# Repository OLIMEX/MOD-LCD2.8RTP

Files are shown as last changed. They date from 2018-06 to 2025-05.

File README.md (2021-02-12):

# MOD-LCD2.8RTP
TFT COLOR LCD module with [UEXT connector](https://www.olimex.com/Products/Modules/) for
[ESP32-EVB](https://www.olimex.com/Products/IoT/ESP32/ESP32-EVB/open-source-hardware) and
[ESP32-POE](https://www.olimex.com/Products/IoT/ESP32/ESP32-POE/open-source-hardware)

**Using MOD-LCD2.8RTP requires non-standard SPI for the display and I2C for the touch screen** 

The non-standard part of the SPI is the lack of MISO which is Data/Command selection pin (refer to controller's datasheet) which has to be set as output.

UEXT pinout:

|UEXT column 1|UEXT column 2|Function|
|---|---|---|
|1 - 3.3V |2 - GND|Power pins|
|3 - NOT USED|4 - NOT USED|UART pins not used|
|5 - SCL|6 - SDA|I2C pins used for touch component|
|7 - D/C|8 - MOSI|SPI pins sans MISO used for display|
|9 - CLK|10 - CS|SPI CLK/CS for display|

If you are using I2C, then the RX wire can also be used to control the brightness. This requires midfying the SJ2 jumper. Refer to the schematic around FET1.

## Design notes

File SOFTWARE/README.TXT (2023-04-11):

##Arduino IDE example:

Tested with Olimex boards - OLIMEXINO-2560, OLIMEXINO-STM32F3, and Olimex ESP32 boards (Olimex ESP32-EVB, ESP32-POE, ESP32-POE-ISO). Refer to the comments in the .ino sketch - make sure to download all the files (library and header files; and not just the .ino).

Folder "graphicstest_olimex_NS2009" contains demo for NS2009 touchscreen.

Folder "graphicstest_olimex" contains demo for STMPE610 touchscreen component.

Basically if touch is not working try the demo in the other folder.

If you use the demo with an ESP32 boards remember to prepare your Arduino IDE environment according to the arduino for ESP32 repository here: https://github.com/espressif/arduino-esp32#installation-instructions

NOTE: You might need to edit the pins in board_pinout.h - for example, if you use ESP32-POE instead of ESP32-EVB, you need to change TFT_CS from 17 to 5 (since ESP32-POE uses pin #5 for chip select).

##PlatformIO example:

Made and tested with Olimex ESP32-EVB using PlatformIO 3.6.0a3

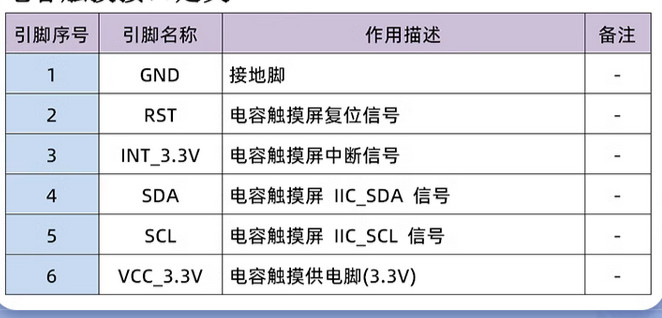
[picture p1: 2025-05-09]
HARDWARE/DOCS/LCD1-pinout2.jpg

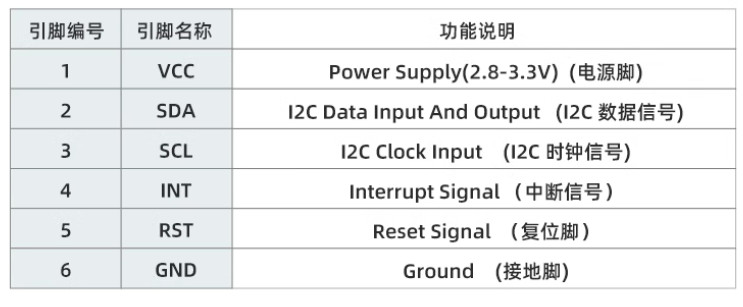
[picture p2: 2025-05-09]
HARDWARE/DOCS/LCD2-pinout2.jpg

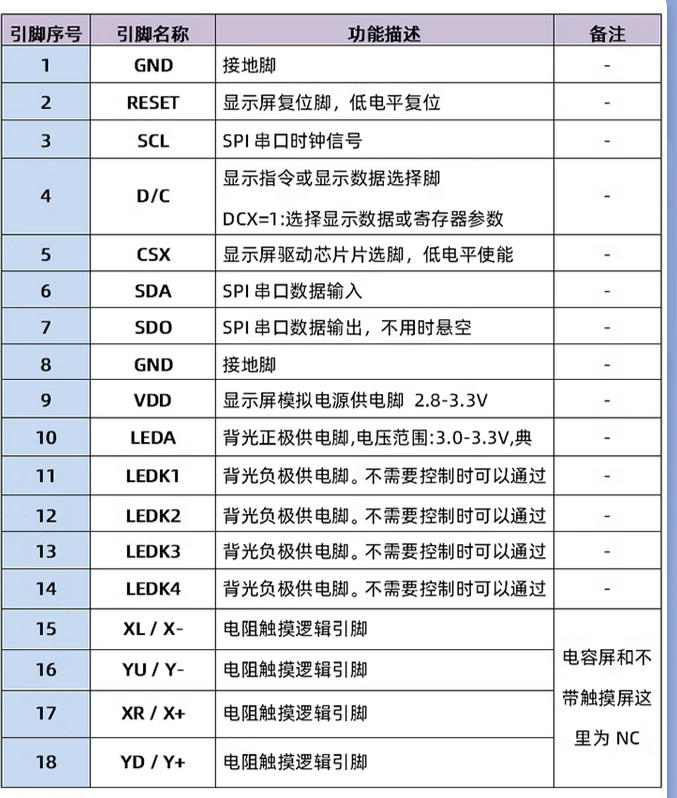
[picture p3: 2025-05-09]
HARDWARE/DOCS/LCD1-pinout.jpg

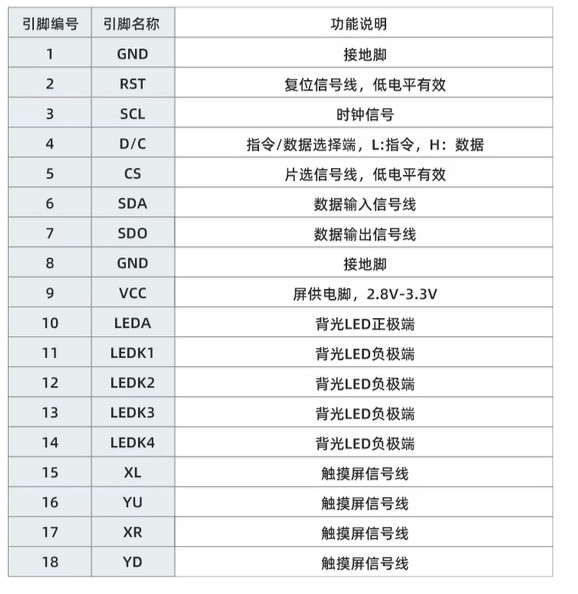
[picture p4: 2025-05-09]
HARDWARE/DOCS/LCD2-pinout.jpg

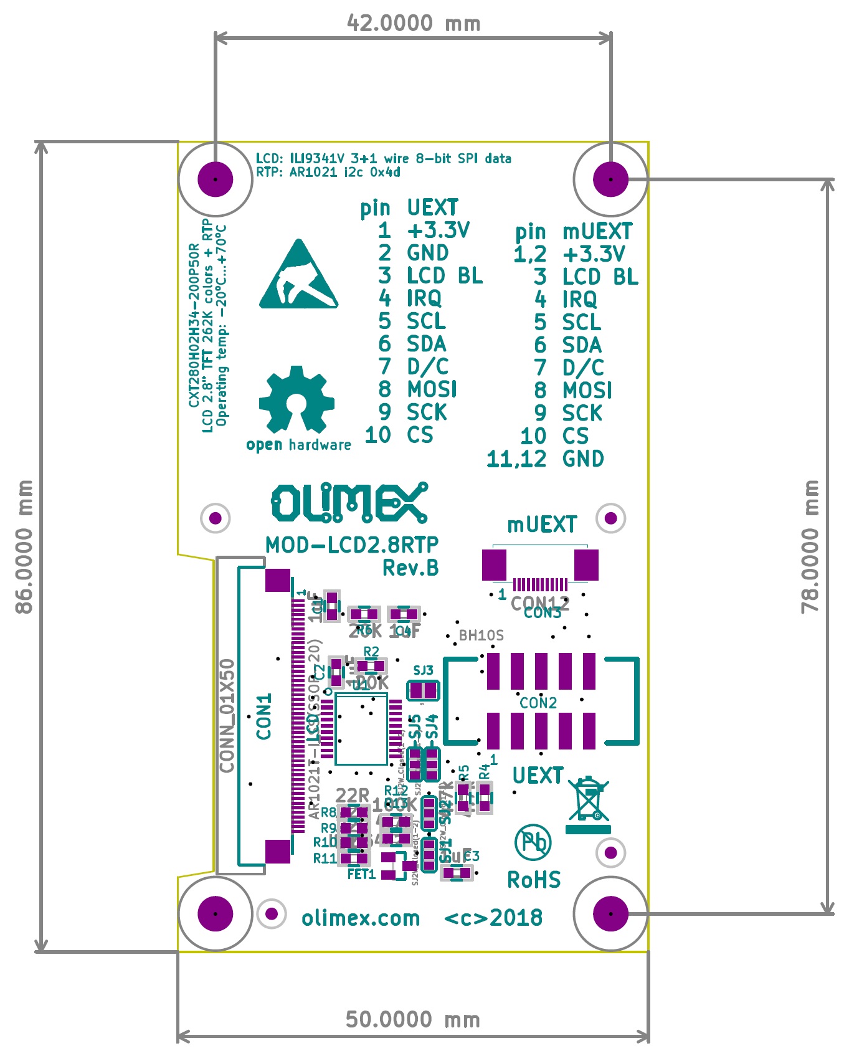
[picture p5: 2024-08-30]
HARDWARE/DIMENSIONS/General-dimensions-LCD28.jpg

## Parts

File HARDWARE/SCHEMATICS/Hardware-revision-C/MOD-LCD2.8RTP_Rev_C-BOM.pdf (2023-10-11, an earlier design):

# MOD-LCD2.8RTP_Rev_C-BOM 09/30/2022

Quantity | Designation | Package | Designator
4 | 22R/R0603 | R_0603 | R1,R2,R3,R4
3 | 4.7k/R0603 | R_0603 | R6,R8,R9
1 | 20k/R0603 | R_0603 | R10
1 | 100k/R0603 | R_0603 | R5
1 | 100nF/Y5V/50VDC/20%/C0603 | C_0603 | C5
4 | 1uF/10V/10%/X5R/C0603 | C_0603 | C1,C3,C4,C6
1 | WPM2015-3/TR | SOT23-3 | FET1
1 | NS2009(MSOP-10) | MSOP-10 | U2
1 | FPV-WZA21-12-LF | FPV-WZB21-12-LF | mUEXT1
1 | P-B-V-10-LF | UEXTM-SMD | UEXT1
1 | CABLE-IDC10-15CM | - | UEXT1
1 | FPV-WZB21-50-LF | FPV-WZB21-50-LF | LCD1
1 | CXT280H02H34-200P50R | - | LCD1
1 | open | SJ | SJ3
4 | Closed(1-2) | SJ_2_SMALL_12_TIED | SJ1,SJ2,SJ4,SJ5
1 | NA(20k/R0603) | R_0603 | R7
1 | NA(1uF/10V/10%/X5R/C0603) | C_0603 | C2
1 | NA(AR1021T-I/SS(SSOP-20)) | SSOP-20W | U1

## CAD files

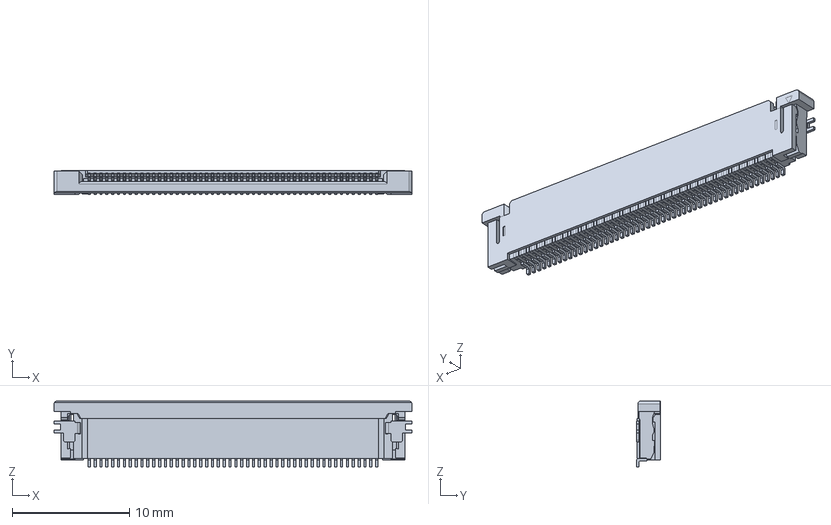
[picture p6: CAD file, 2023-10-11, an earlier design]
HARDWARE/SCHEMATICS/Hardware-revision-C/3d/FPV-WZA21-50-LF_Molex-541045033.stp
30.5 x 2.05 x 5.60 mm

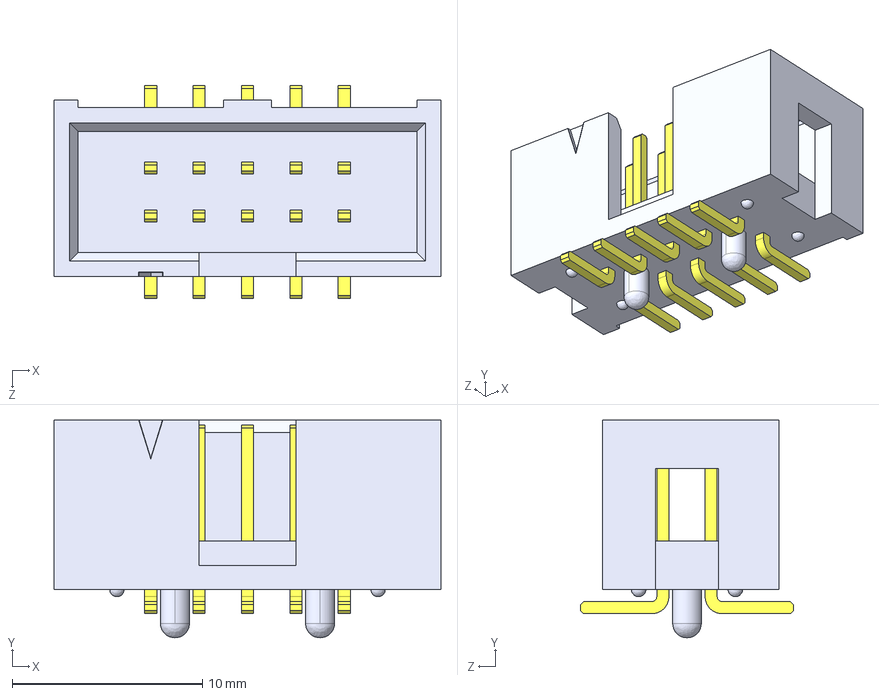
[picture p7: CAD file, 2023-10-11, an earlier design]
HARDWARE/SCHEMATICS/Hardware-revision-C/3d/UEXT-SMD.STEP
20.3 x 11.4 x 11.2 mm
User Library-HTST-105-01-F-DV-A__HTST-105-01-DV-A_header
User Library-HTST-105-01-F-DV-A__HTST-First_Position_Indicator
User Library-HTST-105-01-F-DV-A__T-1S6-05-01-DV_

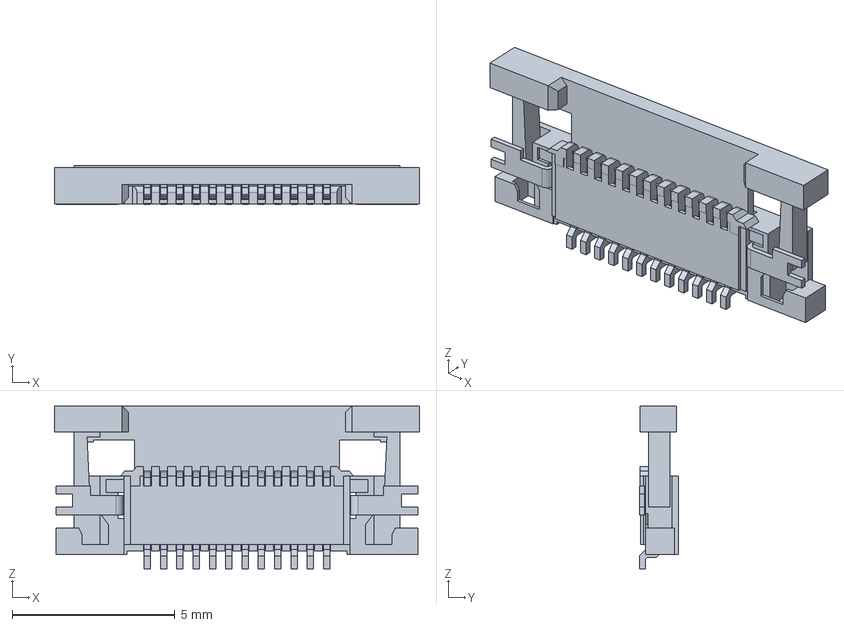
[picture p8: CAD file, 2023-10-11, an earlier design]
HARDWARE/SCHEMATICS/Hardware-revision-C/3d/FPV-WZB21-12-LF_Molex-545481271.stp
11.2 x 1.20 x 5.00 mm

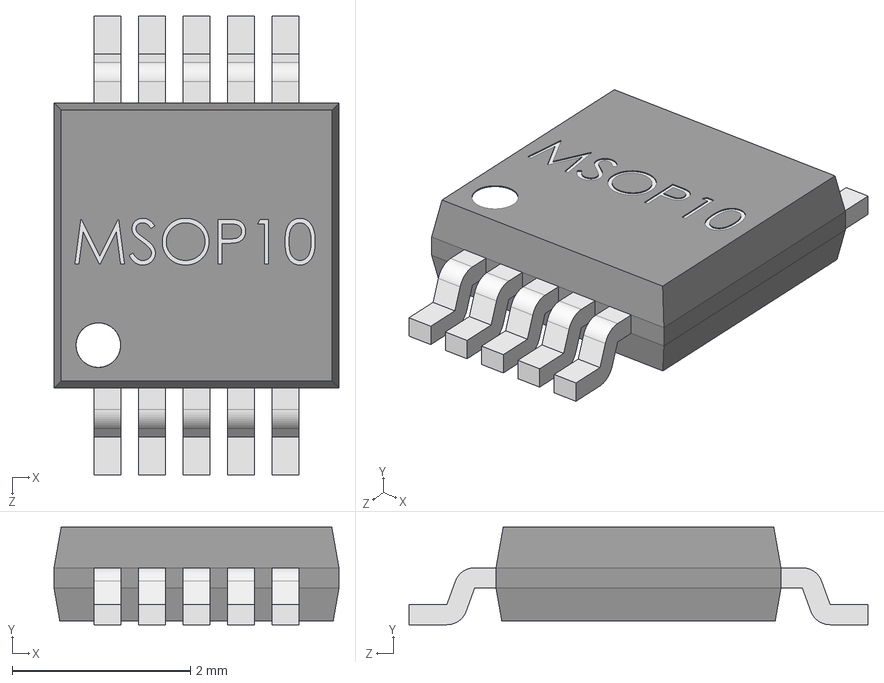
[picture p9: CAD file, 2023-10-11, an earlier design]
HARDWARE/SCHEMATICS/Hardware-revision-C/3d/MSOP10-1.step
3.20 x 1.10 x 5.15 mm

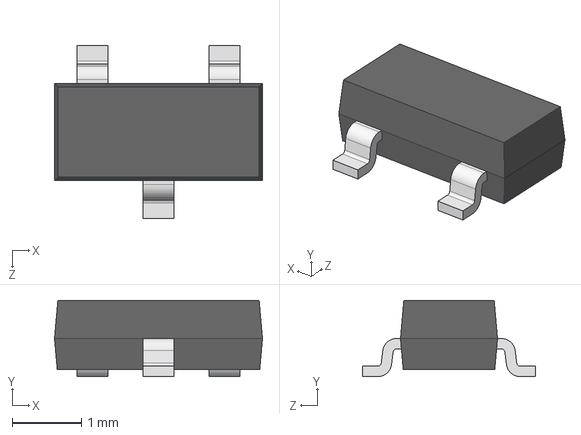
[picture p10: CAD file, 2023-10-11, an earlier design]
HARDWARE/SCHEMATICS/Hardware-revision-C/3d/SOT-23.step
3.00 x 1.10 x 2.50 mm

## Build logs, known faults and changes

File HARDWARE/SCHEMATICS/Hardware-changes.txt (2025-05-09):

=========================================
Hardware changes in revision D
=========================================

1. Changed LCD with LCD-2.8in_BL-YT280S002;
2. Major PCB changes due to the new LCD. Dimensions and mount holes kept the same for compatiblity reasons;
3. Moved design to KiCad v.7.x;
4. Removed  mUEXT.

=========================================
Hardware changes in revision C
=========================================

1. CON3 symbol changed - added symbol with pin <0>;
2. CON1's, SJ3's  footprint changed;
3. Added U2(NS2009(MSOP-10)), C5(100nF) amd C6(1uF);
4. Changed wrong symbol for FET1 from N-channel to P-channel and value from IRML6402 to WPM2015-3/TR;
5. All footprints on the board updated;
6. CON1, CON2, CON3 values changed;
7. CON1 renamed to LCD1; CON2 renamed to UEXT1; CON3 renamed to mUEXT1;
8. Annotation cleared, the whole schematic was reannotated and the pcb was updated;
9. Added CE sign.

=========================================
Hardware revision B
=========================================

Initial board release

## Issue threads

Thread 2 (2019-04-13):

Ili9341 vs spi_master.h

crmabs, 2019-04-13:
Hi,
Good news for the ESP-IDF fanatics: the famous SPI+DMA example works with you product if you initalize the GPIO pins properly. PIN_NUM_DC needs especially to be treated fair otherwise the screen stays white.
  Nothing fancy, just something like this:

```
  gpio_config_t io_conf;
  io_conf.intr_type = (gpio_int_type_t)GPIO_PIN_INTR_DISABLE;
  io_conf.mode = GPIO_MODE_OUTPUT;
  io_conf.pin_bit_mask = 1<<PIN_NUM_DC;
  io_conf.pull_down_en = (gpio_pulldown_t)GPIO_PULLDOWN_DISABLE;
  io_conf.pull_up_en = (gpio_pullup_t)GPIO_PULLUP_DISABLE;

  esp_err_t res;
  res = gpio_config(&io_conf);
  ESP_ERROR_CHECK(res);
```
https://github.com/espressif/esp-idf/tree/master/examples/peripherals/spi_master

I'm aware of the fact that the above mentioned repo is handled by Espressif, this message is just sharing the solution. Tested on Olimex Esp-Evb board + MOD-LCD2.8RTP.

Have a nice day!

DanKoloff, 2019-04-15:
Nice, thanks. Hope this information doesn't get lost!

We also have support for the display in our Arduino package, as shown here: https://github.com/OLIMEX/MOD-LCD2.8RTP/tree/master/SOFTWARE

And we also tested NES emulator here:

https://www.youtube.com/watch?v=v96blCp6uOM

crmabs, 2019-04-15:
So far I didn't dare to post a issue in the esp-idf repo because I have a feeling (not tested yet) that the issue is related to the fact that the Olimex Esp-Evb has some extra electronics wired on those lines and not directly connected with a plain wire.

Yes, the Arduino example works flawlessly no doubt. That gave me hope on the first place.
Btw, it would be nice to have a jumper for the backlight. (not soldered)  Or some detailed docs, the schematic is definitive that's for sure, but not always simple to figure out.
 Food for thought.

Closed 2021-03-16.

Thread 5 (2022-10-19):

Doesn't work with the ESP32-ADF

jwktje, 2022-10-19:
The example doesn't run on the ESP32-ADF. Which pins do I use?

I'm using the ESP32-ADF RevC

I'm also not sure what board to select when flashing. The ESP32-ADF isn't shown in the list of boards to choose from.

DanKoloff, 2022-10-27:
There are demos for ESP32-ADF and MOD-LCD2.8RTP for ESP-IDF, you can find them at ESP32's product page. Exploring these demos might give you ideas on how to get it working under Arduino IDE.

> The example doesn't run on the ESP32-ADF.

Well, ESP32-ADF had no configuration in Board_Pinout.h.

There were configurations for ESP32-POE, ESP32-POE-ISO, ESP32-EVB, OLIMEXINO-2560, OLIMEXINO-STM32F3.

> Which pins do I use?

The pins at the UEXT, trace them in the schematic and add them to Board_Pinout.h, on quick look it seems to be the following pins:

#define TFT_DC 12
#define TFT_CS 15
#define TFT_MOSI 13
#define TFT_CLK 14

> The ESP32-ADF isn't shown in the list of boards to choose from.

You can use "ESP32 Wrover Module" entry, since ESP32-ADF uses ESP32-WROVER. Notice that if you select "ESP32 Wrover Module", then the block to add in Board_Pinout.h would be:

#elif defined ARDUINO_ESP32_DEV
//This is if you select ESP32 Wrover Module
    #define TFT_DC 12
    #define TFT_CS 15
    #define TFT_MOSI 13
    #define TFT_CLK 14
    #define TFT_MISO -1
    #define TFT_RST -1

You would also need to change the pins for the I2C, either in the variant definitions or better in the code directly with Wire.begin(18,23);

To save you some time I also did it and updated the example on the GitHub, download all files and try it yourself.

Closed 2022-10-27.

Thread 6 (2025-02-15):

MOD_LCD2.8RTP + ESP32-POE - SD_MMC

dexterbot80, 2025-02-15:
I'm trying to build a logger based on ESP32-POE, SD_MMC and LCD2.8RTP, I connected the display to the UEXT port and when I activate the logger the display freezes.
Is there a solution that will allow me to use the display connected to the UEXT and the SD slot so that it doesn't freeze anymore?
I also need a network connection to implement MQTT commands.

DanKoloff, 2025-02-18:
Just use other free pins for the SPI for the display, remove the UEXT connector and use wires for attaching the display to free pins. Change the code to work with the new pins assigned for SPI function.

There is multiplexing between the UEXT connector and the SD card. Look in the schematic for the small blue labels near the UEXT1 connector that say "HSPIQ", "HSPID", "HSPICLK" - these are SPI pins that are also routed to the SD card and you need to use other pins for the purpose. SPI pins are important for the display, they are responsible for the picture.

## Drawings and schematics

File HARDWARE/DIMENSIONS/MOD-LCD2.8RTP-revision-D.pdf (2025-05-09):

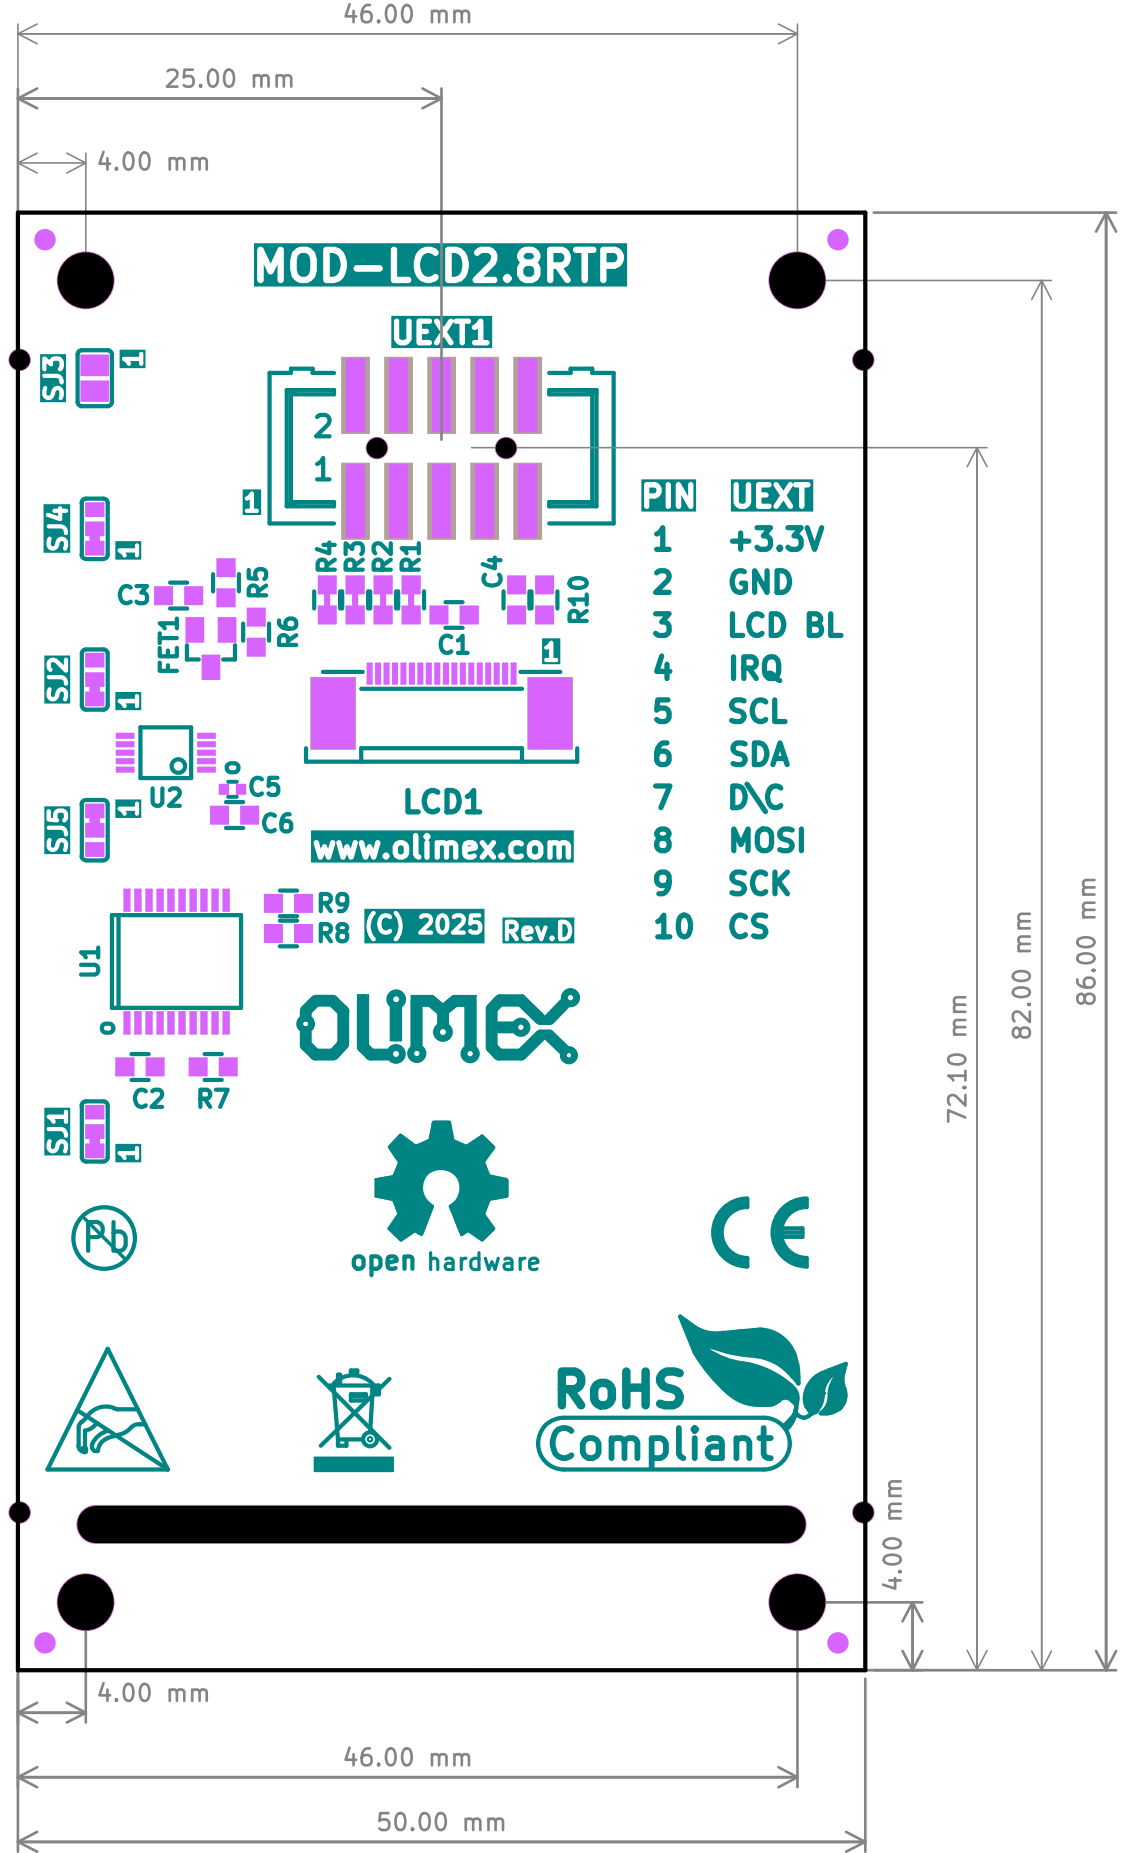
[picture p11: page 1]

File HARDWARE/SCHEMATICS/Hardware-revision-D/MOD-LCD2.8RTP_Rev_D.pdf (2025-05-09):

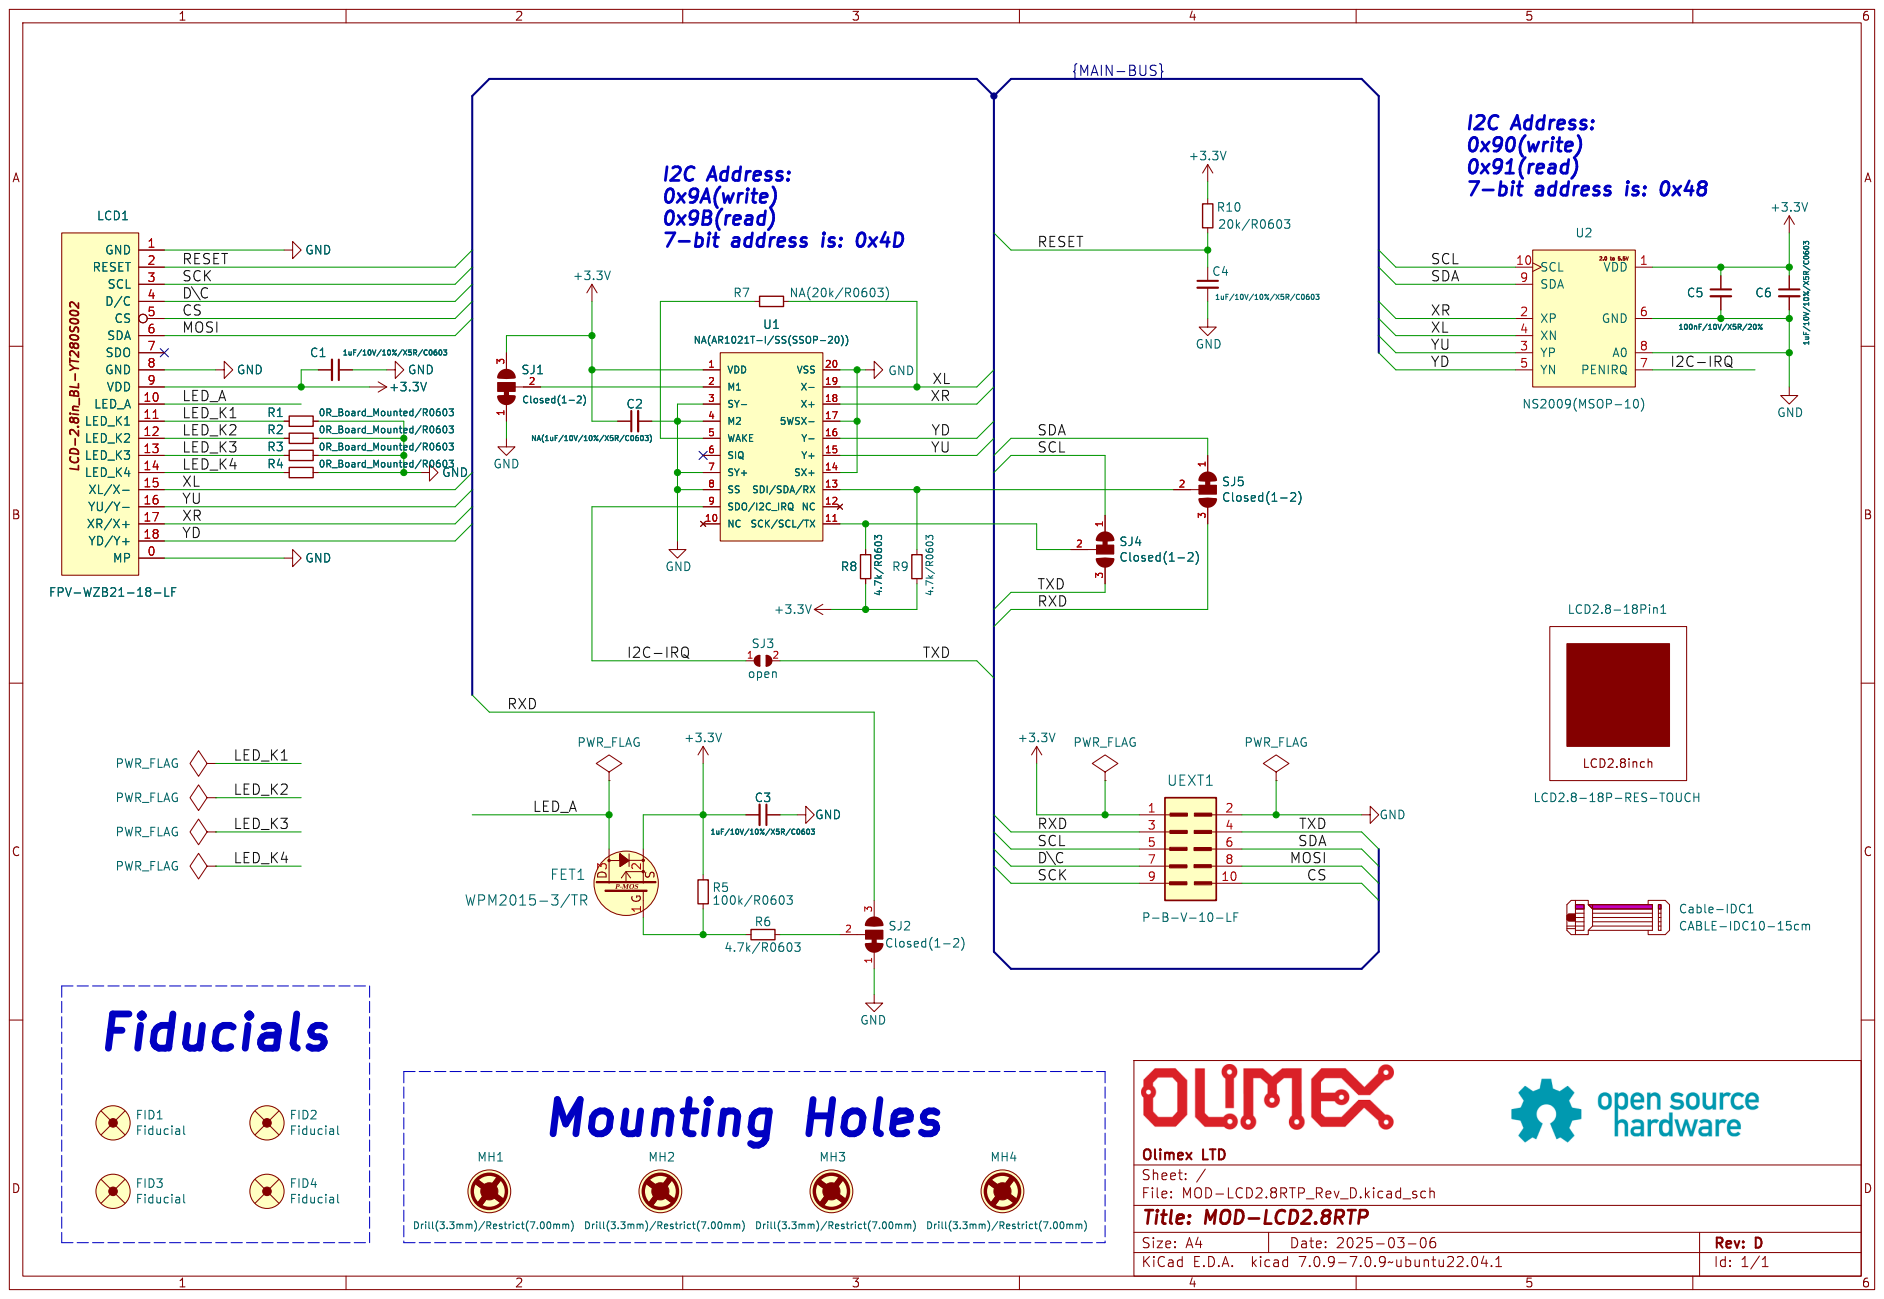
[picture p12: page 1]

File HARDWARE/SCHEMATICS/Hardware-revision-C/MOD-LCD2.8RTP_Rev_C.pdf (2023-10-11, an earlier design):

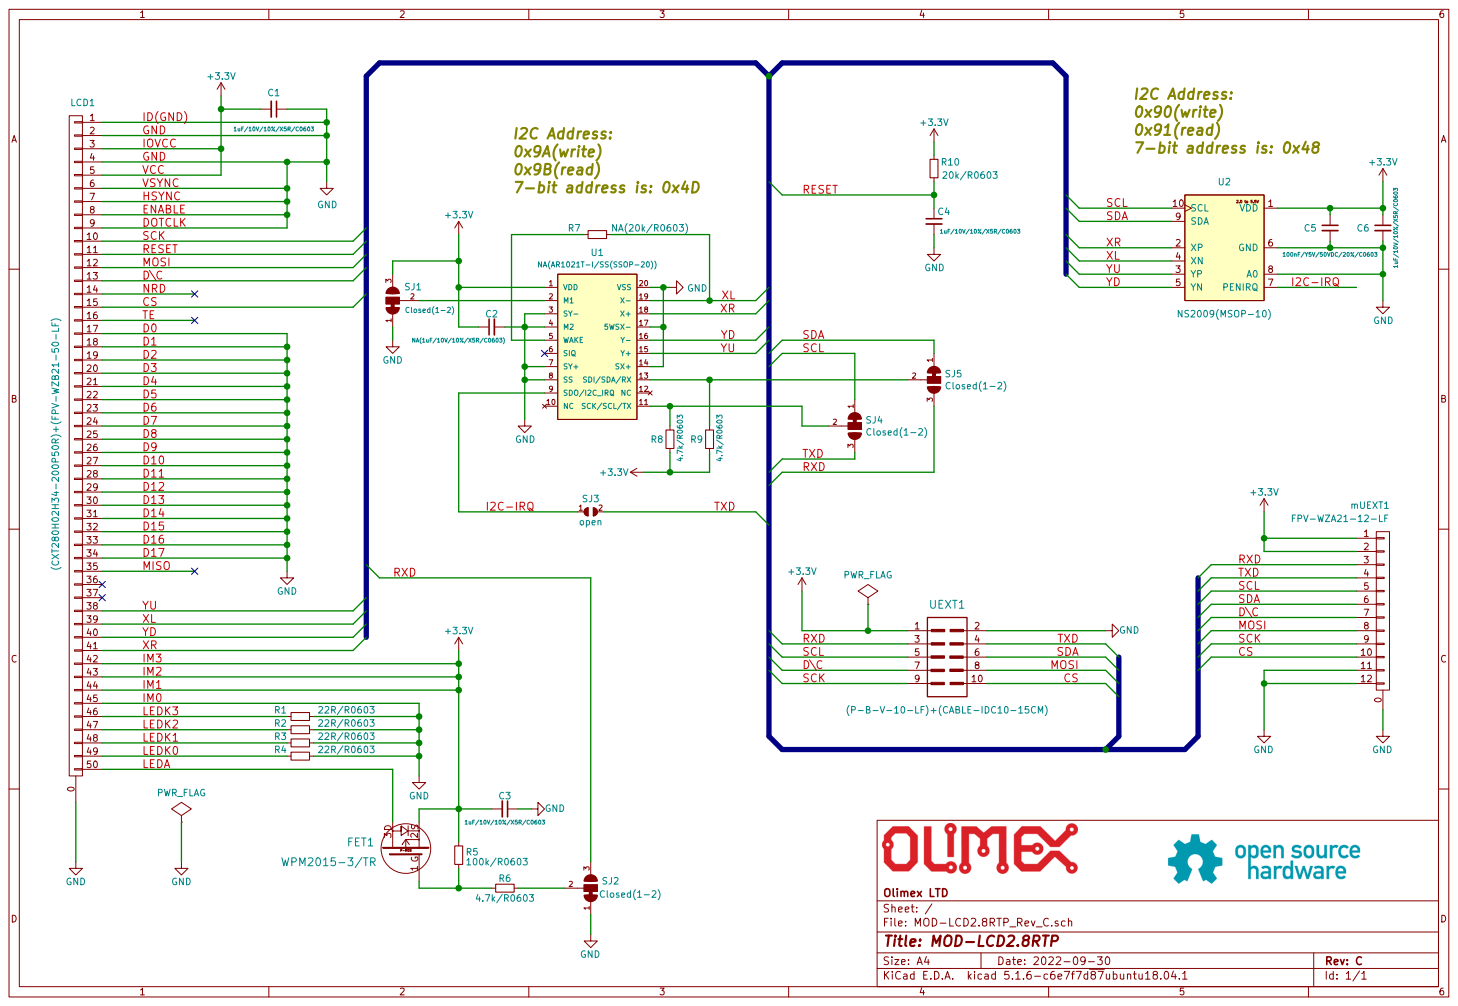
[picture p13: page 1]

3 | IOVCC
8 | D0 GND ENABLE DOTCLK

7 | HSYNC

43 | IM2
44 | IM1
45 | IM0
46
47
48
49

File: MOD-LCD2.8RTP_Rev_C.sch Sheet: / Olimex LTD

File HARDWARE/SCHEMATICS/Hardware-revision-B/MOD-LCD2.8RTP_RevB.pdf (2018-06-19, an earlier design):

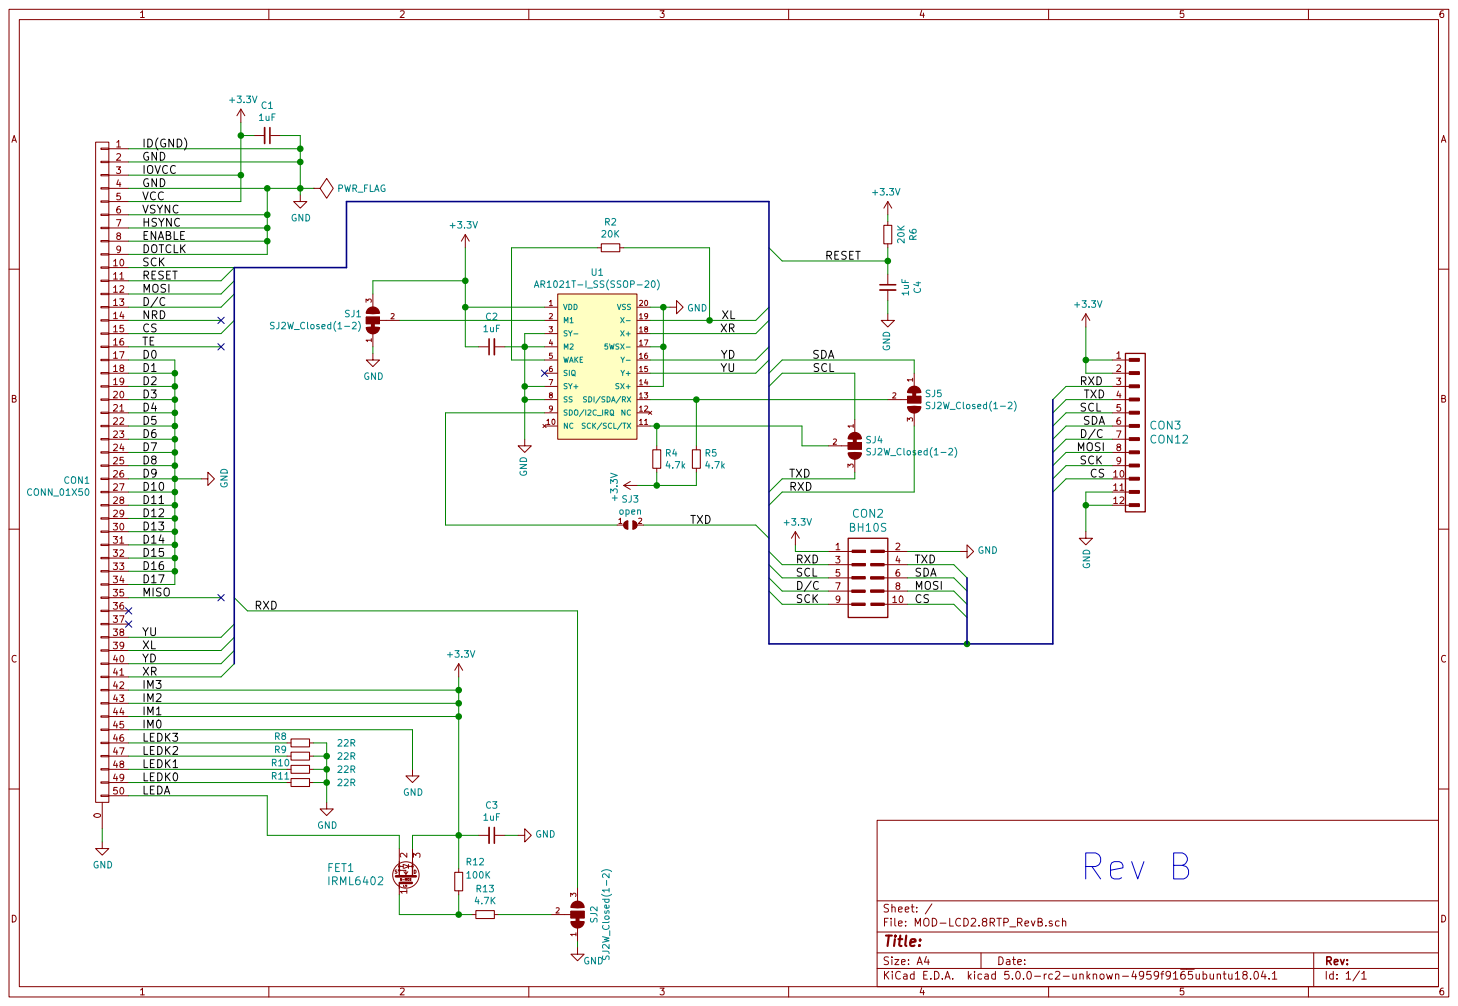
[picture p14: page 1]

GND
IOVCC
VCC

HSYNC
ENABLE DOTCLK

30
31
32
33
34

43 | IM2
44 | IM1
45 | IM0
46
47
48

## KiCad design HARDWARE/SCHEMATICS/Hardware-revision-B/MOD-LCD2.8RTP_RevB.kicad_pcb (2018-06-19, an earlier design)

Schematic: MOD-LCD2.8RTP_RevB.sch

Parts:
C1, C2, C3, C4: 1uF; C_0603_5MIL_DWS
CON1: CONN_01X50; FPV-WZA21-50-LF
CON2: BH10S; UEXTM-SMD
CON3: CON12; FPV-WZB21-12-LF
FET1: IRML6402; SOT23
R2, R6: 20K; R_0603_5MIL_DWS
R4, R5: 4.7k; R_0603_5MIL_DWS
R8, R9, R10, R11: 22R; R_0603_5MIL_DWS
R12: 100K; R_0603_5MIL_DWS
R13: 4.7K; R_0603_5MIL_DWS
SJ1, SJ2, SJ4, SJ5: SJ2W_Closed(1-2); SJ_2_SMALL_12_TIED
SJ3: open; SJ_2_SMALL
U1: AR1021T-I_SS(SSOP-20); SSOP-20

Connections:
+3V3: C1.2, C2.1, C3.2, CON1.3, CON1.5, CON1.42, CON1.43, CON1.44, CON2.1, CON3.1, CON3.2, FET1.3 (D), R4.2, R5.2, R6.1, R12.1, SJ1.3, U1.1 (VDD)
/CS: CON1.15, CON2.10, CON3.10
/D/C: CON1.13, CON2.7, CON3.7
/LEDA: CON1.50, FET1.2 (S)
/LEDK0: CON1.49, R11.2
/LEDK1: CON1.48, R10.2
/LEDK2: CON1.47, R9.2
/LEDK3: CON1.46, R8.2
/MISO: CON1.35
/MOSI: CON1.12, CON2.8, CON3.8
/NRD: CON1.14
/RESET: C4.1, CON1.11, R6.2
/RXD: CON2.3, CON3.3, SJ2.3, SJ5.3
/SCK: CON1.10, CON2.9, CON3.9
/SCL: CON2.5, CON3.5, SJ4.1
/SDA: CON2.6, CON3.6, SJ5.1
/TE: CON1.16
/TXD: CON2.4, CON3.4, SJ3.2, SJ4.3
/XL: CON1.39, R2.2, U1.19 (X-)
/XR: CON1.41 (P4), U1.18 (X+)
/YD: CON1.40, U1.16 (Y-)
/YU: CON1.38, U1.15 (Y+)
GND: C1.1, C2.2, C3.1, C4.2, CON1.0, CON1.1, CON1.2, CON1.4, CON1.6, CON1.7, CON1.8, CON1.9, CON1.17, CON1.18, CON1.19, CON1.20, CON1.21, CON1.22, CON1.23, CON1.24, CON1.25, CON1.26, CON1.27, CON1.28, CON1.29, CON1.30, CON1.31, CON1.32, CON1.33, CON1.34, CON1.45, CON2.2, CON3.0, CON3.11, CON3.12, R8.1, R9.1, R10.1, R11.1, SJ1.1, SJ2.1, U1.3 (SY-), U1.4 (M2), U1.7 (SY+), U1.8 (SS), U1.14 (SX+), U1.17 (5WSX-), U1.20 (VSS)
unnamed: FET1.1 (G), R12.2, R13.2
unnamed: R2.1, U1.5 (WAKE)
unnamed: R4.1, SJ4.2, U1.11 (SCK/SCL/TX)
unnamed: R5.1, SJ5.2, U1.13 (SDI/SDA/RX)
unnamed: R13.1, SJ2.2
unnamed: SJ1.2, U1.2 (M1)
unnamed: SJ3.1, U1.9 (SDO/I2C_IRQ)

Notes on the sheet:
Rev B

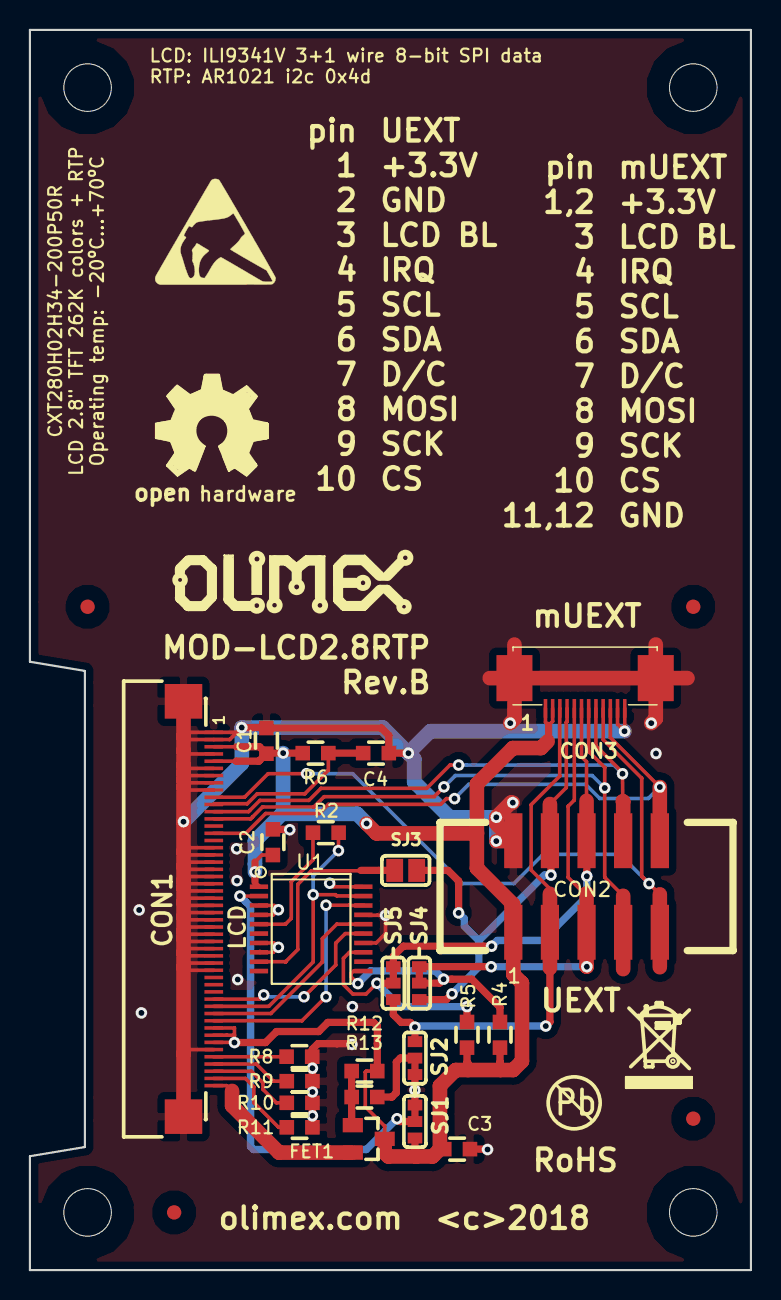
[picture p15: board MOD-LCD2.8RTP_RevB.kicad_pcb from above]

Board: 2 copper layers, 50.0 x 86.0 mm, 32 parts (0 on the bottom side), 27 nets.

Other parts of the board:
MountingHole*: Mounting_hole_3.3mm
MountingHole*#2, MountingHole*#3, MountingHole*#4: Mounting_hole_3.3mm
Ref*: Val**; Fiducial1x3_transp
Ref*#2, Ref*#3, Ref*#4: Val**; Fiducial1x3_transp

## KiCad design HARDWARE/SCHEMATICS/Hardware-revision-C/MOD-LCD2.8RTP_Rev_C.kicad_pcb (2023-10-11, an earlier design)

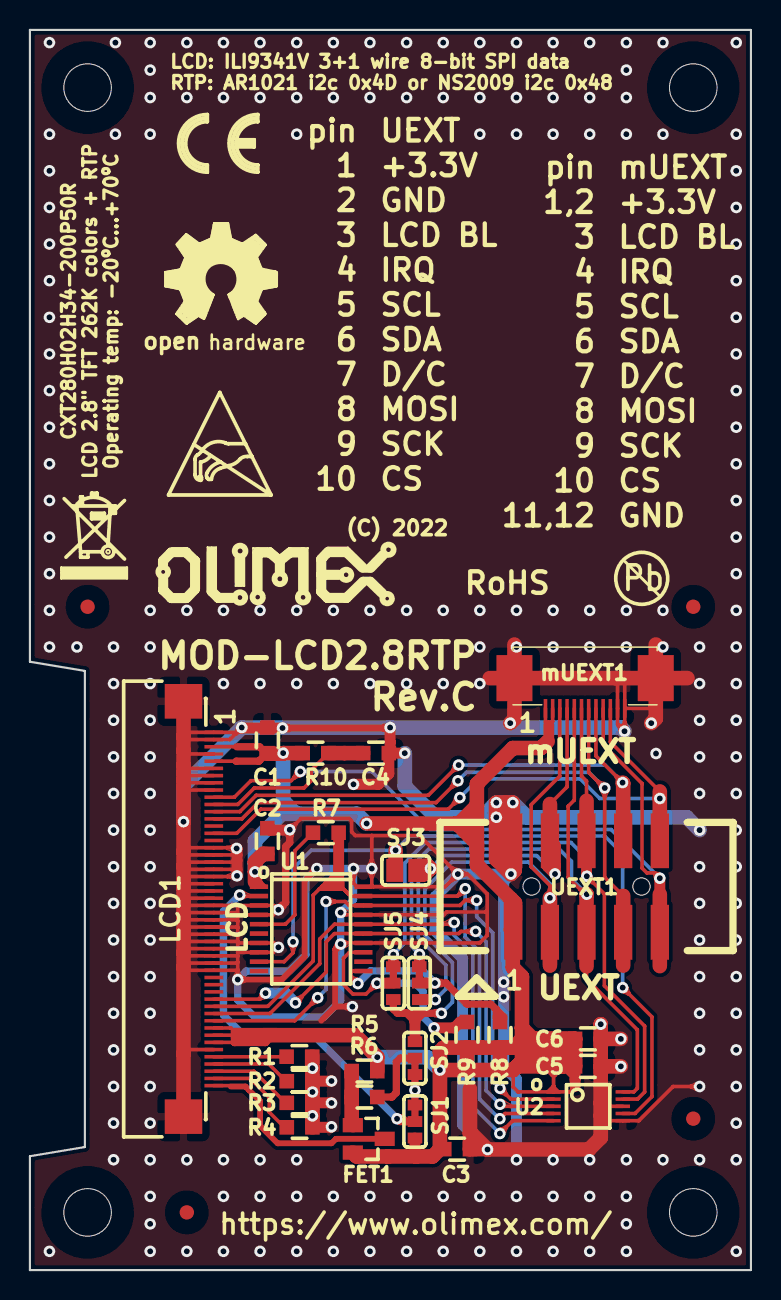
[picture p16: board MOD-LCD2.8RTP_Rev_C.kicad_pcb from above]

Board: 2 copper layers, 50.0 x 86.0 mm, 42 parts (1 on the bottom side), 27 nets.

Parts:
C1, C3, C4, C6: 1uF/10V/10%/X5R/C0603; C_0603_5MIL_DWS
C2: NA(1uF/10V/10%/X5R/C0603); C_0603_5MIL_DWS
C5: 100nF/Y5V/50VDC/20%/C0603; C_0603_5MIL_DWS
FET1: WPM2015-3/TR; SOT23
FID1, FID2, FID3, FID4: Val**; Fiducial1x3_transp
LCD1: (CXT280H02H34-200P50R)+(FPV-WZB21-50-LF); FPV-WZB21-50-LF
Logo_Olimex_1, Logo_Olimex_2: OLIMEX_LOGO_TB
MH1, MH2, MH3, MH4: Mounting_hole_3.3mm
R1, R2, R3, R4: 22R/R0603; R_0603_5MIL_DWS
R5: 100k/R0603; R_0603_5MIL_DWS
R6, R8, R9: 4.7k/R0603; R_0603_5MIL_DWS
R7: NA(20k/R0603); R_0603_5MIL_DWS
R10: 20k/R0603; R_0603_5MIL_DWS
SJ1, SJ2, SJ4, SJ5: Closed(1-2); SJ_2_SMALL_12_TIED
SJ3: open; SJ
Sign_Antistatic: Sign_Antistatic
Sign_CE: CE_Sign
Sign_OSHW: LOGO_OPENHARDWARE_8x8
Sign_PB-Free: LOGO_PBFREE
Sign_Recyclebin: LOGO_RECYCLEBIN_1
U1: NA(AR1021T-I/SS(SSOP-20)); SSOP-20W
U2: NS2009(MSOP-10); MSOP-10_Pitch-0.5mm_3.00x3.00x1.00mm
UEXT1: (P-B-V-10-LF)+(CABLE-IDC10-15CM); UEXTM-SMD
mUEXT1: FPV-WZA21-12-LF; FPV-WZB21-12-LF

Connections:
+3V3: C1.2, C2.1, C3.2, C5.1, C6.1, FET1.2, LCD1.3, LCD1.5, LCD1.42, LCD1.43, LCD1.44, R5.1, R8.2, R9.2, R10.1, SJ1.3, U1.1, U2.1, UEXT1.1, mUEXT1.1, mUEXT1.2
/CS: LCD1.15, UEXT1.10, mUEXT1.10
/D\C: LCD1.13, UEXT1.7, mUEXT1.7
/I2C-IRQ: SJ3.1, U1.9, U2.7
/LEDA: FET1.3, LCD1.50
/LEDK0: LCD1.49, R4.2
/LEDK1: LCD1.48, R3.2
/LEDK2: LCD1.47, R2.2
/LEDK3: LCD1.46, R1.2
/MOSI: LCD1.12, UEXT1.8, mUEXT1.8
/RESET: C4.1, LCD1.11, R10.2
/RXD: SJ2.3, SJ5.3, UEXT1.3, mUEXT1.3
/SCK: LCD1.10, UEXT1.9, mUEXT1.9
/SCL: SJ4.1, U2.10, UEXT1.5, mUEXT1.5
/SDA: SJ5.1, U2.9, UEXT1.6, mUEXT1.6
/TXD: SJ3.2, SJ4.3, UEXT1.4, mUEXT1.4
/XL: LCD1.39, R7.2, U1.19, U2.4
/XR: LCD1.41, U1.18, U2.2
/YD: LCD1.40, U1.16, U2.5
/YU: LCD1.38, U1.15, U2.3
GND: C1.1, C2.2, C3.1, C4.2, C5.2, C6.2, LCD1.0, LCD1.1, LCD1.2, LCD1.4, LCD1.6, LCD1.7, LCD1.8, LCD1.9, LCD1.17, LCD1.18, LCD1.19, LCD1.20, LCD1.21, LCD1.22, LCD1.23, LCD1.24, LCD1.25, LCD1.26, LCD1.27, LCD1.28, LCD1.29, LCD1.30, LCD1.31, LCD1.32, LCD1.33, LCD1.34, LCD1.45, R1.1, R2.1, R3.1, R4.1, SJ1.1, SJ2.1, U1.3, U1.4, U1.7, U1.8, U1.14, U1.17, U1.20, U2.6, U2.8, UEXT1.2, mUEXT1.0, mUEXT1.11, mUEXT1.12
unnamed: FET1.1, R5.2, R6.2
unnamed: R6.1, SJ2.2
unnamed: R7.1, U1.5
unnamed: R8.1, SJ4.2, U1.11
unnamed: R9.1, SJ5.2, U1.13
unnamed: SJ1.2, U1.2

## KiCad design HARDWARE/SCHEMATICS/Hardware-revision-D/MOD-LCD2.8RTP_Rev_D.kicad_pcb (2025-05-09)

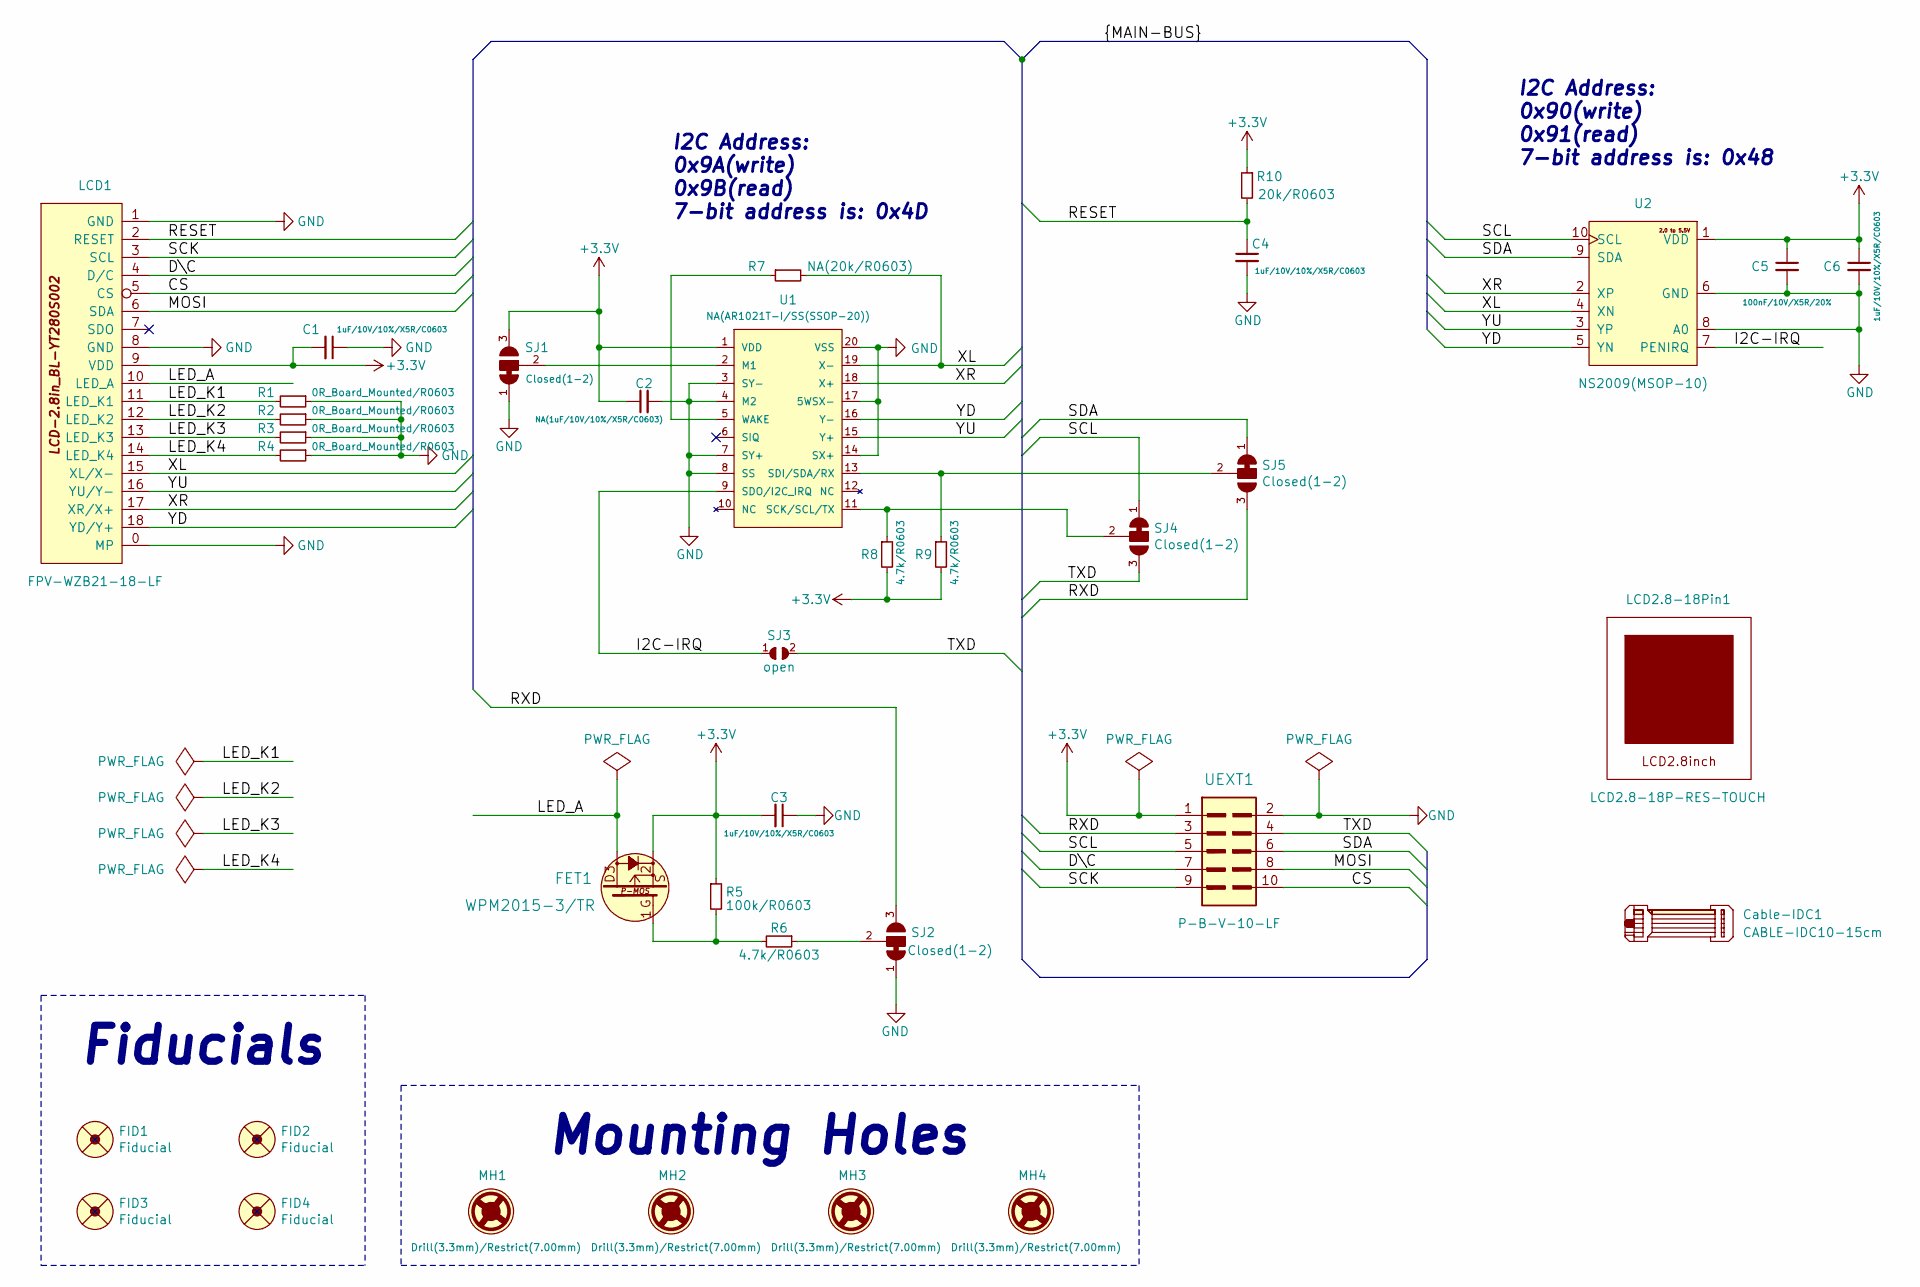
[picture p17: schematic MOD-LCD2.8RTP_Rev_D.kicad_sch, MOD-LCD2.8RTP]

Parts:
C1, C3, C4, C6: 1uF/10V/10%/X5R/C0603; C_0603_5MIL_DWS
C2: NA(1uF/10V/10%/X5R/C0603); C_0603_5MIL_DWS
C5: 100nF/10V/X5R/20%; C_0402_5MIL_DWS
Cable-IDC1: CABLE-IDC10-15cm; Cable-IDC
FET1: WPM2015-3/TR; SOT23
FID1, FID3: Fiducial; Fiducial1x3
FID2, FID4: Fiducial; Fiducial1x3_Paste
LCD1: FPV-WZB21-18-LF; LCD-2.8in_BL-YT280S002(FPV-WZB21-18-LF)
LCD2.8-18Pin1: LCD2.8-18P-RES-TOUCH; LCD2.8-18Pin
MH1, MH2, MH3, MH4: Drill(3.3mm)/Restrict(7.00mm); Mounting_Hole_Drill-3.3mm_Clerance-7mm
R1, R2, R3, R4: 0R_Board_Mounted/R0603; R_0603_5MIL_0R(Board_Mounted)
R5: 100k/R0603; R_0603_5MIL_DWS
R6, R8, R9: 4.7k/R0603; R_0603_5MIL_DWS
R7: NA(20k/R0603); R_0603_5MIL_DWS
R10: 20k/R0603; R_0603_5MIL_DWS
SJ1, SJ2, SJ4, SJ5: Closed(1-2); SJ_2_SMALL_12_TIED
SJ3: open; SJ
U1: NA(AR1021T-I/SS(SSOP-20)); SSOP-20W
U2: NS2009(MSOP-10); MSOP-10_Pitch-0.5mm_3.00x3.00x1.00mm
UEXT1: P-B-V-10-LF; GBH-254-SMT-10

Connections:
+3.3V: C1.2, C2.1, C3.2, C5.1, C6.1, FET1.2, LCD1.9 (VDD), R5.1, R8.2, R9.2, R10.1, SJ1.3, U1.1 (VDD), U2.1 (VDD), UEXT1.1
/CS: LCD1.5 (CS), UEXT1.10
/D\C: LCD1.4 (D/C), UEXT1.7
/I2C-IRQ: SJ3.1, U1.9 (SDO/I2C_IRQ), U2.7 (PENIRQ)
/LED_A: FET1.3, LCD1.10 (LED_A)
/LED_K1: LCD1.11 (LED_K1), R1.2
/LED_K2: LCD1.12 (LED_K2), R2.2
/LED_K3: LCD1.13 (LED_K3), R3.2
/LED_K4: LCD1.14 (LED_K4), R4.2
/MOSI: LCD1.6 (SDA), UEXT1.8
/RESET: C4.1, LCD1.2 (RESET), R10.2
/RXD: SJ2.3, SJ5.3, UEXT1.3
/SCK: LCD1.3 (SCL), UEXT1.9
/SCL: SJ4.1, U2.10 (SCL), UEXT1.5
/SDA: SJ5.1, U2.9 (SDA), UEXT1.6
/TXD: SJ3.2, SJ4.3, UEXT1.4
/XL: LCD1.15 (XL/X-), R7.2, U1.19 (X-), U2.4 (XN)
/XR: LCD1.17 (XR/X+), U1.18 (X+), U2.2 (XP)
/YD: LCD1.18 (YD/Y+), U1.16 (Y-), U2.5 (YN)
/YU: LCD1.16 (YU/Y-), U1.15 (Y+), U2.3 (YP)
GND: C1.1, C2.2, C3.1, C4.2, C5.2, C6.2, LCD1.0 (MP), LCD1.1 (GND), LCD1.8 (GND), R1.1, R2.1, R3.1, R4.1, SJ1.1, SJ2.1, U1.3 (SY-), U1.4 (M2), U1.7 (SY+), U1.8 (SS), U1.14 (SX+), U1.17 (5WSX-), U1.20 (VSS), U2.6 (GND), U2.8 (A0), UEXT1.2
unnamed: FET1.1, R5.2, R6.2
unnamed: R6.1, SJ2.2
unnamed: SJ1.2, U1.2 (M1)
unnamed: R8.1, SJ4.2, U1.11 (SCK/SCL/TX)
unnamed: R9.1, SJ5.2, U1.13 (SDI/SDA/RX)
unnamed: R7.1, U1.5 (WAKE)

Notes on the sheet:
Fiducials
I2C Address: 0x90(write) 0x91(read) 7-bit address is: 0x48
Mounting Holes
I2C Address: 0x9A(write) 0x9B(read) 7-bit address is: 0x4D

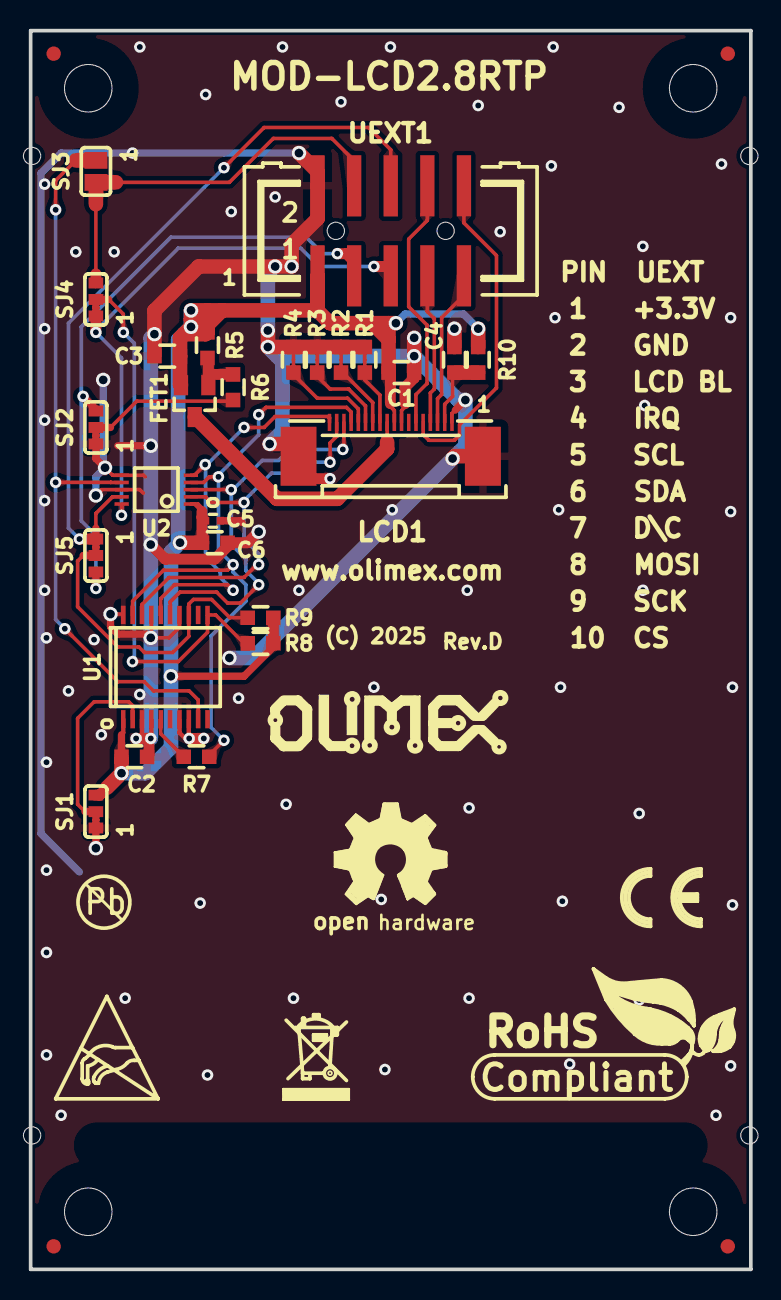
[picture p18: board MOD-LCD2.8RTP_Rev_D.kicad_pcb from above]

Board: 2 copper layers, 50.0 x 86.0 mm, 44 parts (1 on the bottom side), 27 nets.

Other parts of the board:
Logo_Olimex_1, Logo_Olimex_2: OLIMEX_LOGO_TB
Sign_Antistatic: Sign_Antistatic
Sign_CE: CE_Sign
Sign_OSHW: LOGO_OPENHARDWARE_8x8
Sign_PB-Free: LOGO_PBFREE
Sign_Recyclebin: LOGO_RECYCLEBIN_1
Sign_RoHS_1: Sign_RoHS_1

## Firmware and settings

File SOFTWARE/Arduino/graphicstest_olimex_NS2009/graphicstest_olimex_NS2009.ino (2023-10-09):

/***************************************************
  This is an example made by Adafruit and modifed by Olimex for MOD-LCD2.8RTP
  This demo was tested with Olimex MOD-LCD2.8RTP and ESP32-EVB.
  The boards were connected via UEXT connector and cable.
  
  Make sure to establish proper hardware connections with your board.
  The display requires SPI, the touschreen I2C. Refer to Board_Pinout.h.
  
  The original example is a GFX example for the Adafruit ILI9341 Breakout and Shield
  ----> http://www.adafruit.com/products/1651

  Check out the link above for Adafruit's tutorials and wiring diagrams
  These displays use SPI to communicate, 4 or 5 pins are required to
  interface (RST is optional)
  Adafruit invests time and resources providing the open source code,
  please support Adafruit and open-source hardware by purchasing
  products from Adafruit!

  Written by Limor Fried/Ladyada for Adafruit Industries.
  MIT license, all text above must be included in any redistribution
 ****************************************************/

 // In order to work you have to install Adafruit GFX Library
 // To do so go to:
 // Main menu --> Sketch --> Inlcude Librariy --> Manage Libraries...
 // In the search box filter "Adafruit GFX Library" and install it
 // Tested with version 1.2.3 of the library

#include "Wire.h"
#include "Board_Pinout.h"
#include "Adafruit_GFX.h"
#include "Adafruit_ILI9341.h"
#include "NS2009.h"


#ifdef  ARDUINO_OLIMEXINO_STM32F3
Adafruit_ILI9341 tft = Adafruit_ILI9341(TFT_CS, TFT_DC, TFT_MOSI, TFT_CLK, TFT_RST, TFT_MISO);
#else
Adafruit_ILI9341 tft = Adafruit_ILI9341(TFT_CS, TFT_DC);
#endif

#define MODE_DRAW_PIXELS    0
#define MODE_DRAW_RECTANGLE 1
#define MODE_DRAW_CIRCLE    2

#define TEXT_HEIGHT 8
#define TEXT_WIDTH  6

NS2009  TS(false, true);
int Mode=MODE_DRAW_PIXELS, ActiveColor = ILI9341_WHITE;

void Print_Text (int X, int Y, int TextColor, int TextSize, char Text[])
{
  tft.setCursor(X, Y);
  tft.setTextColor(TextColor);
  tft.setTextSize(TextSize);
  tft.println(Text);
}

void Print_Text_In_Box (int X, int Y, int W, int H, int TextColor, int TextSize, char Text[])
{
  int Len = strlen (Text)*TEXT_WIDTH;
  Print_Text (X+(W-Len)/2, Y+(H-TEXT_HEIGHT)/2, TextColor, TextSize, Text);
}

void Draw_Outlined_Rectangle(int X, int Y, int W, int H, int OutlineColor, int InsideColor)
{
  tft.fillRoundRect (X, Y, W, H, 0, InsideColor);
  tft.drawRoundRect (X, Y, W, H, 0, OutlineColor);
}

void Draw_Palette ()
{
  Draw_Outlined_Rectangle (  0,   0,  30,  30, ILI9341_BLACK, ILI9341_WHITE);
  Draw_Outlined_Rectangle ( 30,   0,  30,  30, ILI9341_BLACK, ILI9341_RED);
  Draw_Outlined_Rectangle ( 60,   0,  30,  30, ILI9341_BLACK, ILI9341_YELLOW);
  Draw_Outlined_Rectangle ( 90,   0,  30,  30, ILI9341_BLACK, ILI9341_GREEN);
  Draw_Outlined_Rectangle (120,   0,  30,  30, ILI9341_BLACK, ILI9341_CYAN);
  Draw_Outlined_Rectangle (150,   0,  30,  30, ILI9341_BLACK, ILI9341_BLUE);
  Draw_Outlined_Rectangle (180,   0,  30,  30, ILI9341_BLACK, ILI9341_MAGENTA);
  Draw_Outlined_Rectangle (210,   0,  30,  30, ILI9341_BLACK, ILI9341_BLACK);
}

void Draw_ActiveColor ()
{
  // active color
  Draw_Outlined_Rectangle (  0,  30, 240,  30, ILI9341_BLACK, ActiveColor);
  Print_Text_In_Box       (  0,  30, 240,  30, ~ActiveColor, 1, "Fill Screen");
}

void Draw_Modes ()
{
  // modes
  Draw_Outlined_Rectangle (  0,  60,  80,  30, ILI9341_BLACK, ILI9341_LIGHTGREY);
  Print_Text_In_Box       (  0,  60,  80,  30, ILI9341_BLACK, 1, "Pixel");
  Draw_Outlined_Rectangle ( 80,  60,  80,  30, ILI9341_BLACK, ILI9341_DARKCYAN);
  Print_Text_In_Box       ( 80,  60,  80,  30, ILI9341_BLACK, 1, "Rectangle");
  Draw_Outlined_Rectangle (160,  60,  80,  30, ILI9341_BLACK, ILI9341_ORANGE);
  Print_Text_In_Box       (160,  60,  80,  30, ILI9341_BLACK, 1, "Circle");

  // outline the active mode
  tft.drawFastHLine       (  0,  90, 240, ILI9341_BLACK);
  switch (Mode)
  {
    case MODE_DRAW_PIXELS:
      tft.drawRoundRect (  0,  60, 80, 30, 0, ILI9341_WHITE);
      Serial.printf ("Drawing pixels option selected!\n\r");
    break;
    case MODE_DRAW_RECTANGLE:
      tft.drawRoundRect ( 80,  60, 80, 30, 0, ILI9341_WHITE);
      Serial.printf ("Drawing a rectangle option selected!\n\r");
    break;
    case MODE_DRAW_CIRCLE:
      tft.drawRoundRect (160,  60, 80, 30, 0, ILI9341_WHITE);
      Serial.printf ("Drawing a circle option selected!\n\r");
    break;
  }
}

void Draw_Frame ()
{
  Draw_Palette ();
  Draw_ActiveColor ();
  Draw_Modes ();
}

void Handle_Touch ()
{
  if (TS.Y<90)  // frame area
  {
    if (TS.Y<30)  // palette area
    {
      if      (TS.X< 30)  // white color area
        ActiveColor = ILI9341_WHITE;
      else if (TS.X< 60)  // red color area
        ActiveColor = ILI9341_RED;
      else if (TS.X< 90)  // yellow color area
        ActiveColor = ILI9341_YELLOW;
      else if (TS.X<120)  // green color area
        ActiveColor = ILI9341_GREEN;
      else if (TS.X<150)  // cyan color area
        ActiveColor = ILI9341_CYAN;
      else if (TS.X<180)  // blue color area
        ActiveColor = ILI9341_BLUE;
      else if (TS.X<210)  // magenta color area
        ActiveColor = ILI9341_MAGENTA;
      else if (TS.X<240)  // black color area
        ActiveColor = ILI9341_BLACK;
      Draw_ActiveColor ();
      Serial.printf ("New color selected!\n\r");
    }
    else if (TS.Y<60) // fill screen area
    {
      tft.fillRoundRect (0, 90, 240, 230, 0, ActiveColor);
      Serial.printf ("Screen area filled with the selected color!\n\r");
    }
    else if (TS.Y<90) // mode area
    {
      if      (TS.X <  80)  // pixel mode area
        Mode = MODE_DRAW_PIXELS;
      else if (TS.X < 160)  // rectangle mode area
        Mode = MODE_DRAW_RECTANGLE;
      else if (TS.X < 240)  // circle mode area
        Mode = MODE_DRAW_CIRCLE;
      Draw_Modes ();
    }
  }
  else  // drawing area
  {
    int PX=TS.X, PY=TS.Y, R;
    switch (Mode)
    {
      case MODE_DRAW_PIXELS:
        while (TS.Touched)
        {
          if (TS.Y>=90)
          {
            tft.drawPixel (TS.X, TS.Y, ActiveColor);
            Serial.printf ("Drawn pixel at %d %d!\n\r", TS.X, TS.Y);
          }
          else
            Serial.printf ("Invalid coordinates!\n\r", TS.X, TS.Y);
          TS.Scan();
        }
      break;
      case MODE_DRAW_RECTANGLE:
        Serial.printf ("First corner of the rectangle is at %d %d. Touch to again to point the opposite corner!\n\r", TS.X, TS.Y);
        while (TS.CheckTouched ());
        TS.ScanBlocking ();
        tft.fillRoundRect (min(PX, TS.X), min(PY, TS.Y), abs(TS.X-PX), abs(TS.Y-PY), 0, ActiveColor);
        Draw_Frame ();
        Serial.printf ("Rectangle drawn!\n\r");
      break;
      case MODE_DRAW_CIRCLE:
        Serial.printf ("Center of the circle is at %d %d. Touch to again to point a point of the circle!\n\r", TS.X, TS.Y);
        while (TS.CheckTouched ());
        TS.ScanBlocking ();
        R = sqrt( (PX-TS.X) * (PX-TS.X) + (PY-TS.Y) * (PY-TS.Y) );
        tft.drawCircle (PX, PY, R, ActiveColor);
        Draw_Frame ();
        Serial.printf ("Circle drawn!\n\r");
      break;
    };
  }
}

void setup()
{
  Serial.begin (115200);
  Wire.begin();
  pinMode(TFT_DC, OUTPUT);
  tft.begin();  // default SPI frequency 40MHz
  //tft.begin(30000000);  // lowers SPI frequency to 30MHz if you use long UEXT cable (or UEXTx5)
  tft.fillScreen(ILI9341_WHITE);
  Draw_Frame ();
}

void loop ()
{
  TS.ScanBlocking ();
  Serial.printf ("Screen touched!\n\r");
  Handle_Touch ();
  while (TS.CheckTouched ());
  Serial.printf ("Screen released!\n\r");
}

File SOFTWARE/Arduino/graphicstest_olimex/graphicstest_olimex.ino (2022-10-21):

/***************************************************
  This is an example made by Adafruit and modifed by Olimex for MOD-LCD2.8RTP
  This demo was tested with Olimex MOD-LCD2.8RTP and ESP32-EVB and OLIMEXINO-2560.
  The boards were connected via UEXT connector and cable.
  
  Make sure to establish proper hardware connections with your board.
  The display requires SPI, the touschreen I2C. Refer to Board_Pinout.h.
  
  The original example is a GFX example for the Adafruit ILI9341 Breakout and Shield
  ----> http://www.adafruit.com/products/1651

  Check out the link above for Adafruit's tutorials and wiring diagrams
  These displays use SPI to communicate, 4 or 5 pins are required to
  interface (RST is optional)
  Adafruit invests time and resources providing the open source code,
  please support Adafruit and open-source hardware by purchasing
  products from Adafruit!

  Written by Limor Fried/Ladyada for Adafruit Industries.
  MIT license, all text above must be included in any redistribution
 ****************************************************/

 // In order to work you have to install Adafruit GFX Library
 // To do so go to:
 // Main menu --> Sketch --> Inlcude Librariy --> Manage Libraries...
 // In the search box filter "Adafruit GFX Library" and install it
 // Tested with version 1.2.3 of the library


#include "Board_Pinout.h"
#include "SPI.h"
#include "Adafruit_GFX.h"
#include "Adafruit_ILI9341.h"
#include "Wire.h"
#include "Adafruit_STMPE610.h"

// This is calibration data for the raw touch data to the screen coordinates
#define TS_MINX 290
#define TS_MINY 285
#define TS_MAXX 7520
#define TS_MAXY 7510
#define TS_I2C_ADDRESS 0x4d


Adafruit_STMPE610 ts = Adafruit_STMPE610();

// Size of the color selection boxes and the paintbrush size
#define BOXSIZE 40

Adafruit_ILI9341 tft = Adafruit_ILI9341(TFT_CS, TFT_DC, TFT_MOSI, TFT_CLK, TFT_RST, TFT_MISO);

//if there is problem with this consturctor for some boards try
//#ifdef  ARDUINO_OLIMEXINO_STM32F3
//Adafruit_ILI9341 tft = Adafruit_ILI9341(TFT_CS, TFT_DC);

uint8_t tp[5];

void setup() {
        // TODO: Power Up UEXT if 32U4

   delay(1000);
   Serial.begin (115200);
   //while (!Serial);
   Serial.print ("Demo started");

  tft.begin();

#if (defined ARDUINO_ESP32_WROVER_KIT) || (defined ARDUINO_ESP32_DEV)
Wire.begin(18,23);
#else
Wire.begin();
#endif

   pinMode(TFT_DC, OUTPUT);
  // read diagnostics (optional but can help debug problems)
  //uint8_t x = tft.readcommand8(ILI9341_RDMODE);
   delay(1000);

   ts.begin(TS_I2C_ADDRESS);


}


void loop(void) {

// This is just a draw some data Demo

// Clear Screen
tft.fillScreen(ILI9341_BLACK);
// Set some fancy background
testFastLines(ILI9341_DARKGREY,ILI9341_DARKCYAN);

// Print "current date and time"
tft.setCursor(5,5);
tft.setTextColor(ILI9341_WHITE);  tft.setTextSize(2);
tft.println("29-05-18      11:28"); //TODO: Print the real date and time


// Print "room temperature"
tft.setCursor(85,50);
tft.setTextColor(ILI9341_GREEN);  tft.setTextSize(4);
tft.println("22");//TODO: Print the real room temperature
tft.setCursor(148,50);
tft.println("C");
tft.drawCircle(138, 54, 4, ILI9341_GREEN);
tft.drawCircle(138, 54, 5, ILI9341_GREEN);
tft.setCursor(78,85);
tft.setTextColor(ILI9341_GREEN);  tft.setTextSize(1);
tft.println("ROOM TEMPERATURE");


// Now print Message box wit two yes/no buttons
tft.fillRoundRect(10,120, 220, 190, 8, ILI9341_OLIVE);
tft.drawRoundRect(10,120, 220, 190, 8, ILI9341_WHITE);

tft.setTextColor(ILI9341_WHITE);  tft.setTextSize(2);
tft.fillRoundRect(20,150, 200, 80,8, ILI9341_BLUE);
tft.setCursor(90, 165);
tft.println("Save");
tft.setCursor(40, 190);
tft.println("new settings?");
tft.drawRoundRect(20,150, 200, 80, 8, ILI9341_WHITE);
// Get the choise
bool answer = Get_yes_no();

if (answer == true)
{
  // Some animation while "write to eeprom"
testFilledRects(ILI9341_DARKGREEN,ILI9341_DARKCYAN);
tft.setCursor(80, 150);
tft.setTextColor(ILI9341_WHITE);  tft.setTextSize(3);
tft.println("Done!");
} else   tft.fillScreen(ILI9341_RED);
// fill screen red to show negative choise
delay(1000);
}


unsigned long testFastLines(uint16_t color1, uint16_t color2) {
  unsigned long start;
  int           x, y, w = tft.width(), h = tft.height();

  tft.fillScreen(ILI9341_BLACK);
  start = micros();
  for(y=0; y<h; y+=5) tft.drawFastHLine(0, y, w, color1);
  for(x=0; x<w; x+=5) tft.drawFastVLine(x, 0, h, color2);

  return micros() - start;
}

unsigned long testFilledRects(uint16_t color1, uint16_t color2) {
  unsigned long start, t = 0;
  int           n, i, i2,
                cx = tft.width()  / 2 - 1,
                cy = tft.height() / 2 - 1;

  tft.fillScreen(ILI9341_BLACK);
  n = min(tft.width(), tft.height());
  for(i=n; i>0; i-=6) {
    i2    = i / 2;
    start = micros();
    tft.fillRect(cx-i2, cy-i2, i, i, color1);
    t    += micros() - start;
    // Outlines are not included in timing results
    tft.drawRect(cx-i2, cy-i2, i, i, color2);
    yield();
  }

  return t;
}

bool Get_yes_no(void){
TS_Point p;
    tft.setTextColor(ILI9341_WHITE);  tft.setTextSize(3);

    tft.fillRoundRect(20,250, 100, 50,8, ILI9341_RED);
    tft.setCursor(56, 265);
    tft.println("NO");
    tft.drawRoundRect(20,250, 100, 50, 8, ILI9341_WHITE);

    tft.fillRoundRect(120,250, 100, 50,8, ILI9341_GREEN);
    tft.setCursor(144, 265);
    tft.println("YES");
    tft.drawRoundRect(120,250, 100, 50, 8, ILI9341_WHITE);


while (1){
      delay(50);
    p = ts.getPoint();

    if (p.z != 129){


      p.x = map(p.x, TS_MINX, TS_MAXX, 0, tft.width());
      p.y = map(p.y, TS_MINY, TS_MAXY, 0, tft.height());
      p.y = 320 - p.y;

      //  tft.fillCircle(p.x, p.y, 5, ILI9341_YELLOW);


    if ((p.y > 250) && (p.y<300)){

      if ((p.x> 20) && (p.x < 220))
            if (p.x>120)
            {
              tft.fillRoundRect(120,250, 100, 50,8, ILI9341_OLIVE);
              tft.setCursor(144, 265);
              tft.println("YES");
              tft.drawRoundRect(120,250, 100, 50, 8, ILI9341_WHITE);

              delay(500);
              return true;
            }
                   else{

                     tft.fillRoundRect(20,250, 100, 50,8, ILI9341_OLIVE);
                     tft.setCursor(56, 265);
                     tft.println("NO");
                     tft.drawRoundRect(20,250, 100, 50, 8, ILI9341_WHITE);

                        delay(500);
                     return false;
                   }

    }

  }
}
}

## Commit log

2020-11-04 Add UEXT pinout defines for ESP32-PoE
2021-02-01 Update
    Corrected #if to match the correct preprocessor define macros of the respetive board.
2021-02-25 Update
    Arduino example patched to work with Olimexino-STM32F
2023-10-09 Update graphicstest_olimex_NS2009.ino
    Added commented line with SPI initialization with lower frequency (30MHz) in case of usage of longer cable or UEXTx5
2023-10-11 Update
    Uploaded hardware revision C files
    [FPV-WZA21-50-LF_Molex-541045033.stp, FPV-WZB21-12-LF_Molex-545481271.stp, MOD-LCD2.8RTP.Rev.B.BOM.ods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]
2025-05-09 Update
    New hardware revision D
    [FPV-WZA21-50-LF_Molex-541045033.stp, FPV-WZB21-12-LF_Molex-545481271.stp, MOD-LCD2.8RTP.Rev.B.BOM.ods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]
2025-05-09 Update
    Added more info about PCB changes.

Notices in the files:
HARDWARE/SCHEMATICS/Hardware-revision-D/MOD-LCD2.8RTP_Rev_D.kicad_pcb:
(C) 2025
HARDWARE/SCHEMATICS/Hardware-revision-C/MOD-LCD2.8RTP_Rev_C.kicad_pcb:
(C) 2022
